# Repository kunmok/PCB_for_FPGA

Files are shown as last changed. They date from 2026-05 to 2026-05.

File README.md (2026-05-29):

# XEM7310 FPGA Breakout Board

Custom breakout / interface board for the
[Opal Kelly XEM7310](https://opalkelly.com/products/xem7310/) FPGA module, designed by
**Kunmo Kim** in Altium Designer at the **Berkeley Wireless Research Center (BWRC)**.

It mates to the XEM7310 through two mezzanine connectors and fans the FPGA's scan-chain,
analog, and digital signals out to the main/DUT board —
[pcb-for-128GSPS-adc-based-serdes](https://github.com/kunmok/pcb-for-128GSPS-adc-based-serdes) —
over a Samtec FFSD cable, while generating the bank I/O supplies and providing the level
shifting, clock probes, debug, and I²C support needed for bring-up and characterization.

XEM7310 FPGA Breakout Board (v0.5)

> 📷 Photo shows the older **v0.5**; the latest revision fixes several bugs and uses a slightly
> cheaper BOM.
> 📄 Full schematic drawing: [`FPGA_breakout_board.pdf`](FPGA_breakout_board.pdf).

## At a glance

| | |
|---|---|
| FPGA module | Opal Kelly XEM7310 |
| PCB | 4-layer; fabricated & assembled by [JLCPCB](https://jlcpcb.com/) |
| `MC2` bank | LVCMOS12 — 1.2 V (TPS7A5701, adjustable) |
| `MC1` bank | LVCMOS33 — 3.3 V (TLV1117LV33) |
| Power in | 5 V — barrel jack / banana / VBUS, TVS-protected |
| Power-up order | +5 V → +1.2 V (VCCO_MC2) → +3.3 V (VCCO_MC1) |
| Main-board link | Samtec FFSD cable, ≈100 Ω, 100 Ω series-terminated |
| Debug / probe | JTAG (ILA), 2× SMA (50 Ω), I²C (Qwiic) |

## Power

Input is 5 V via the barrel jack (`J_JACK`), banana jacks (`VDCIN_CONN` / `GND_CONN`), or
VBUS, protected by a TVS diode (`D3`). Two on-board LDOs generate the FPGA bank I/O supplies:

| Bank | I/O standard | Supply | LDO |
|---|---|---|-----|
| `MC2` | LVCMOS12 | 1.2 V — adjustable via `P1V2_POT` (Bourns 3266W-1-503, 50 kΩ) | TPS7A5701 (`U5`) |
| `MC1` | LVCMOS33 | 3.3 V | TLV1117LV33 (`U1`) |

`MC1` runs at 3.3 V because the on-chip **LT3074**'s enable input requires a 3.3 V signal.

> ⚠️ **Power-up sequence (external 1.2 V supply)** — required for correct operation, not to
> prevent damage. Follow the schematic order **+5 V → +1.2 V (VCCO_MC2) → +3.3 V (VCCO_MC1)**.
> Before driving 1.2 V into `VCCO_MC2`, isolate the XEM7310's own supply path (**do not touch
> FB8** per the schematic) to avoid back-driving the module. See Opal Kelly's
> [Powering the XEM7310](https://docs.opalkelly.com/xem7310/powering-the-xem7310/) for the
> module's power requirements.

The XEM7310 `PG_5V5` power-good flag crosses the voltage boundary via **two-step level
shifting** (two SN74LV1T34 buffers, `U_LS1` / `U_LS2`) — the reason the sequence above matters.

## Clock-test quad (`CLKQUAD`)

Optional scan-chain interface (`J_CLKQUAD`, Samtec STMM-107) for clock testing — used **only**
to measure **CLK jitter** and **ILRO lock status**, otherwise kept off. Because high scan speed
isn't needed, it runs through a dedicated **SN74AXC8T245** translator (`U2`) instead of LVCMOS
I/O, keeping the FPGA banks free.

## High-speed ADC data interface (SMA)

Two SMA connectors (Bel Cinch 142-0761-881, 26.5 GHz) on **50 Ω microstrip** carry:

- **`MEM_CLK`** — 100 MHz clock, FPGA → SerDes board.
- **`MEM_DATA_I`** — 100 Mbps retimed ADC output data, SerDes board → FPGA. Tested up to
  **200 Mbps**; likely capable of more, but untested beyond what this setup needed.

Together these two signals drive the SerDes board's **on-chip memory**: `MEM_CLK` clocks the
read-out while `MEM_DATA_I` streams the stored samples back to the FPGA, letting the FPGA read
out the retimed ADC data samples held in memory.

## FFSD cable

Scan / analog / digital signals reach the
[main board](https://github.com/kunmok/pcb-for-128GSPS-adc-based-serdes) over a Samtec FFSD
ribbon cable (`J_ESHF`, ESHF-125-01-L-D-SM), whose characteristic impedance was measured at
**≈100 Ω** in the lab. Matching **100 Ω series resistors** (`R4`–`R31`, 0402) sit close to the
connector on the driver side.

## Control & configuration

Most configuration signals originate from the **XEM7310 FPGA**, with a **Microchip
MCP2221A** USB-to-I²C/UART bridge providing an alternate path for some of them.
- I2C Control: Special thanks to @nonNoise for their [PyMCP2221A repository](https://github.com/nonNoise/PyMCP2221A), which was instrumental in implementing I2C control via the MCP2221A for this project.

**Scan chains** — all scan-chain signals are driven by the FPGA. The main board carries two
independent chains: a **5-pin** chain for analog-circuit control and a **7-pin** chain for
digital-circuit control. Both chains run at **12.5 Mbps**. The 7-pin chain runs on a
**two-phase non-overlapping clock**, making it immune to hold-time violations.

**LDO enable** — normally driven by the FPGA, but can alternatively be driven from the
**MCP2221A GPIO** pins.

**I²C** — normally handled by the **MCP2221A** at **100 kbps**; the FPGA can drive it as a
fallback.

## Connectors & key parts

| Function | Part | Designator(s) |
|---|---|---|
| XEM7310 mezzanine | Samtec BTE-040-01-F-D-A (0.8 mm) | `MC1`, `MC2` |
| FFSD cable | Samtec ESHF-125-01-L-D-SM | `J_ESHF` |
| CLKQUAD header | Samtec STMM-107-02-L-D | `J_CLKQUAD` |
| SMA clk/data (26.5 GHz) | Bel Cinch 142-0761-881 | `J_MEM_CLK`, `J_MEM_DATA` |
| JTAG (ILA, 2×7, 2 mm) | Molex 87831-1420 | `J_JTAG` |
| I²C — Qwiic / headers | Würth 61300311121 / Samtec TSW | `P1` / `J_SCL*`, `J_SDA*` |
| USB-to-I²C/UART bridge | Microchip MCP2221A | `U3` |
| 1.2 V LDO (5 A, adj.) | TI TPS7A5701RTER | `U5` |
| 3.3 V LDO (1 A) | TI TLV1117LV33DCYR | `U1` |
| Level translator (CLKQUAD) | TI SN74AXC8T245RHLR | `U2` |
| Level shifter (PG_5V5) | TI SN74LV1T34DBVR | `U_LS1`, `U_LS2` |
| 100 Ω series term (0402) | Panasonic ERJ-2RKF1000X | `R4`–`R31` |
| TVS / jack / banana | SMAJ6.0CA / CUI PJ-102AH / Keystone 575-4 | `D3` / `J_JACK` / `*_CONN` |

Full BOM:
[`FPGA_breakout_board_BOM.xlsx`](Project%20Outputs%20for%20FPGA_breakout_board/FPGA_breakout_board_BOM.xlsx).

## Files

4-layer stack-up (Top / two inner planes / Bottom); DRC passes with **0 violations**.

```
BoardTop.SchDoc                Top-level schematic
FPGA_breakout_board_v1.PcbDoc  PCB layout
FPGA_breakout_board.PrjPcb     Altium project
FPGA_breakout_board.pdf        Schematic + fabrication drawings
FPGA_breakout_board.OutJob     Output-generation job
Component/                     Symbols, footprints, 3D/STEP models, vendor libs
Project Outputs for .../       Gerbers, NC drill, BOM, pick & place, DRC report
```

Open `FPGA_breakout_board.PrjPcb` in Altium Designer. Run the `.OutJob` to regenerate
manufacturing outputs; ready-to-send Gerbers are in `Project Outputs .../Gerber.zip`.

## Author

Designed by **Kunmo Kim** — [kunmo.kim0225@gmail.com](mailto:kunmo.kim0225@gmail.com) ·
[kunmok.github.io](https://kunmok.github.io)

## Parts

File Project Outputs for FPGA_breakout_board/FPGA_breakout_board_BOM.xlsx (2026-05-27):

Line # | Name | Description | Designator | Quantity | Manufacturer 1 | Manufacturer Part Number 1 | Supplier 1 | Supplier Part Number 1 | Supplier Unit Price 1 | Supplier Subtotal 1
 | MTG | Mounting hole | MH1, MH2, MH3, MH4, MH5, MH6, MH7, MH8 | 8
1 | LLL1U4R60G435ME22D | Cap Ceramic Monolithic 4.3uF 20% 4V X5R 15% 02404 (0610M) | C1, C2, C4, C5, C6, C7, C8, C10, C11, C13, C16, C17, C18, C20 | 14 | Murata | LLL1U4R60G435ME22D | Digikey | 490-LLL1U4R60G435ME22DCT-ND | 0.073 | 1.02
2 | ESHF-125-01-L-D-SM | No Description Available | J_ESHF | 1 | Samtec | ESHF-125-01-L-D-SM | Digikey | SAM15560-ND | 7.15 | 7.15
3 | STMM-107-02-L-D | Connector Header Surface Mount 14 position 0.079 (2.00mm) | J_CLKQUAD | 1 | Samtec | STMM-107-02-L-D | Mouser | 200-STMM10702LD | 4.58 | 4.58
4 | EEF-CX0J101R | CAP ALUM POLY 100UF 20% 6.3V SMD | C9 | 1 | Panasonic | EEF-CX0J101R | Avnet | 62W7349 | 1.19 | 1.19
5 | SMAJ6.0CAHE3/5A | Transient Voltage Suppressor, 6.40 to 231 V, 6 V Stand-off Voltage, Bi-Directional, -55 to 155 degC, 2-pin DO-214AC, Pb-Free, Tape and Reel | D3 | 1 | Vishay Semiconductors | SMAJ6.0CAHE3_A/H | Mouser | 78-SMAJ6.0CAHE3_A/H | 0.61 | 0.61
6 | LTST-C190KGKT | LED GREEN CLEAR CHIP SMD | D_1V2, D_5V5 | 2 | Vishay Lite-On | LTST-C190KGKT | Mouser | 859-LTST-C190KGKT | 0.13 | 0.26
7 | PJ-102AH | DC power connector - high current | J_JACK | 1 | CUI Devices | PJ102AH | Digikey | CP-102AH-ND | 0.76 | 0.76
8 | TSW-102-07-G-S | CONN HEADER VERT 2POS 2.54MM | J_SCL1, J_SCL2, J_SDA1, J_SDA2 | 4 | Samtec | TSW-102-07-G-S | Avnet | TSW-102-07-G-S | 0.147 | 0.588
9 | 575-4 | Banana Jack, Non-Insulated, 1-Pin THD, RoHS, Bulk | GND_CONN, VDCIN_CONN | 2 | Keystone Electronics | 575-4 | Newark | 99H8227 | 0.773 | 1.55
10 | 06035C104KAT2A | General Purpose Ceramic Capacitor, 0603, 100nF, 10%, X7R, 15%, 50V | C3 | 1 | Kyocera AVX | 06035D104KAT2A | Newark | 95W9226 | 0.005 | 0.005
11 | 87831-1420 | Header, Pitch 2 mm, 2 x 7 Position, Height 6.4 mm, Tail Length 2.5 mm, -55 to 105 degC, RoHS, Tube | J_JTAG | 1 | Molex | 87831-1420 | Arrow Electronics | 87831-1420 | 0.84 | 0.84
12 | 5019 |  | J_GP0, J_GP1, J_GP2, J_GP3, J_RST, J_VBUS | 6 | Keystone Electronics | 5019 | Newark | 59Y8500 | 0.283 | 1.7
13 | ERJ-3EKF1000V |  | R_SCL, R_SDA | 2 | Panasonic | ERJ-3EKF1000V | Newark | 85Y8496 | 0.099 | 0.198
14 | ERJ-8ENF2001V |  | R1, R2, R3 | 3 | Panasonic | ERJ-8ENF2001V | Newark | 65T8855 | 0.019 | 0.057
15 | 5001 | PC TEST POINT MINIATURE BLACK | J_GND1, J_GND2, J_GND3, J_GND4 | 4 | Keystone Electronics | 5001 | Newark | 62W5135 | 0.155 | 0.62
16 | 142-0761-881 | SMA High Freq End Launch Jack Receptacle, PCB Mount, 10 MIL Pin, 26.5 GHz, 50 Ohm, -65 to 165 degC, Round Body Radius 6.27 mm, Body Length 9.52 mm, RoHS | J_MEM_CLK, J_MEM_DATA | 2 | Bel Cinch | 142-0761-881
17 | 5000 | PC TEST POINT MINIATURE RED | J_1V0, J_1V2, J_VCCO_MC1 | 3 | Keystone Electronics | 5000 | Newark | 07J9695 | 0.131 | 0.393
18 | BTE-040-01-F-D-A | 0.8mm high-density header | MC1, MC2 | 2 | Samtec | BTE-040-01-F-D-A | Digikey | SAM9060-ND | 3.38 | 6.76
19 | 61300311121 |  | P1 | 1 | Wurth Electronics | 61300311121 | Digikey | 732-5316-ND | 0.12 | 0.12
20 | 878980304 | No Description Available | P1V2_EN | 1 | Molex | 87898-0304 | Digikey | WM20562-ND | 0.7 | 0.7
21 | 3266W-1-503LF | No Description Available | P1V2_POT | 1 | Bourns | 3266W-1-503LF | Avnet | 3266W-1-503LF | 2.77 | 2.77
22 | TLV1117LV33DCYR | Single Output LDO, 1 A, Fixed 3.3 V Output, 2 to 5.5 V Input, 4-pin SOT-223 (DCY), -40 to 125 degC, Green (RoHS & no Sb/Br) | U1 | 1 | Texas Instruments | TLV1117LV33DCYR | Mouser | 595-TLV1117LV33DCYR | 0.22 | 0.22
23 | ERJ-3EKF2002V |  | R8, R9, R10 | 3 | Panasonic | ERJ-3EKF2002V | Mouser | 667-ERJ-3EKF2002V | 0.12 | 0.36
24 | ERJ-3EKF4022V | RES SMD 40.2K OHM 1% 1/10W 0603 | R7 | 1 | Panasonic | ERJ-3EKF4022V | Newark | 65T8448 | 0.005 | 0.005
25 | MMBT3904TT1G | General Purpose Transistor, NPN Silicon, 3-Pin SC-75, Pb-Free, Tape and Reel | Q1 | 1 | onsemi | MMBT3904TT1G | Avnet | 88H4787 | 0.032 | 0.032
26 | ERJ-2RKF1000X | Chip Resistor, 100 Ohm, +/- 1%, 100 mW, -55 to 155 degC, 0402 (1005 Metric), RoHS, Tape and Reel | R4, R5, R6, R11, R12, R13, R14, R15, R16, R17, R18, R19, R24, R25, R26, R27, R28, R29, R30, R31 | 20 | Panasonic | ERJ-2RKF1000X | Avnet | 64R5246 | 0.017 | 0.34
27 | TSW-107-07-G-S | CONN HEADER VERT 7POS 2.54MM | J1, J2 | 2 | Samtec | TSW-107-07-G-S | Avnet | TSW-107-07-G-S | 0.15568 | 0.31136
28 | SN74LV1T34DBVR | IC BUF NON-INVERT 5.5V SOT23-5 | U_LS1, U_LS2 | 2 | Texas Instruments | SN74LV1T34DBVR | Arrow Electronics | SN74LV1T34DBVR | 0.162 | 0.324
29 | TPS7A5701RTER | No Description Available | U5 | 1 | Texas Instruments | TPS7A5701RTER | Mouser | 595-TPS7A5701RTER | 11.72 | 11.72
30 | ERJ-8GEYJ202V |  | R20, R21 | 2 | Panasonic | ERJ-8GEYJ202V | Digikey | P2.0KECT-ND | 0.13 | 0.26
31 | SN74AXC8T245RHLR | IC TRNSLTR BIDIRECTIONAL 24VQFN | U2 | 1 | Texas Instruments | SN74AXC8T245RHLR | Arrow Electronics | SN74AXC8T245RHLR | 0.99 | 0.99

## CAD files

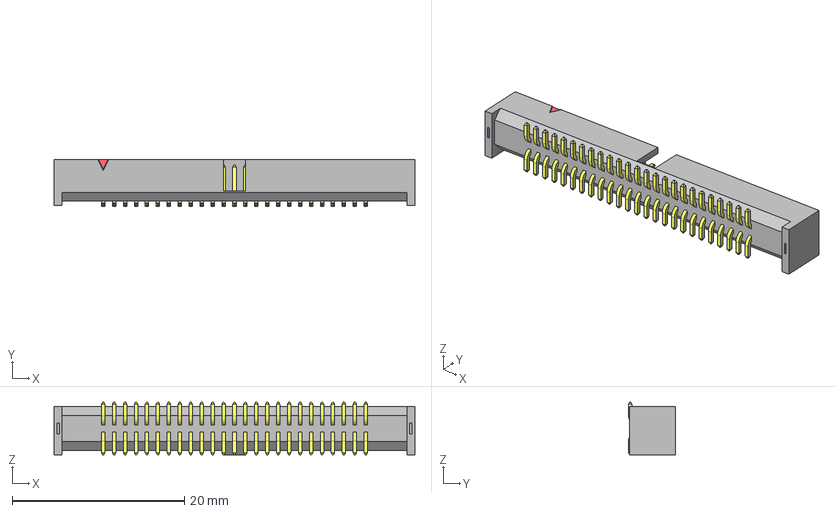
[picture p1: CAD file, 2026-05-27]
Component/ESHF_conn/ESHF-125-01-L-D-SM.stp
41.9 x 5.46 x 6.10 mm
ESHF-125-01-L-D-SM_t
ESHF-125-01-L-D-SM_p
ESHF-125-01-L-D-SM_k
ESHF-125-01-L-D-SM_tr

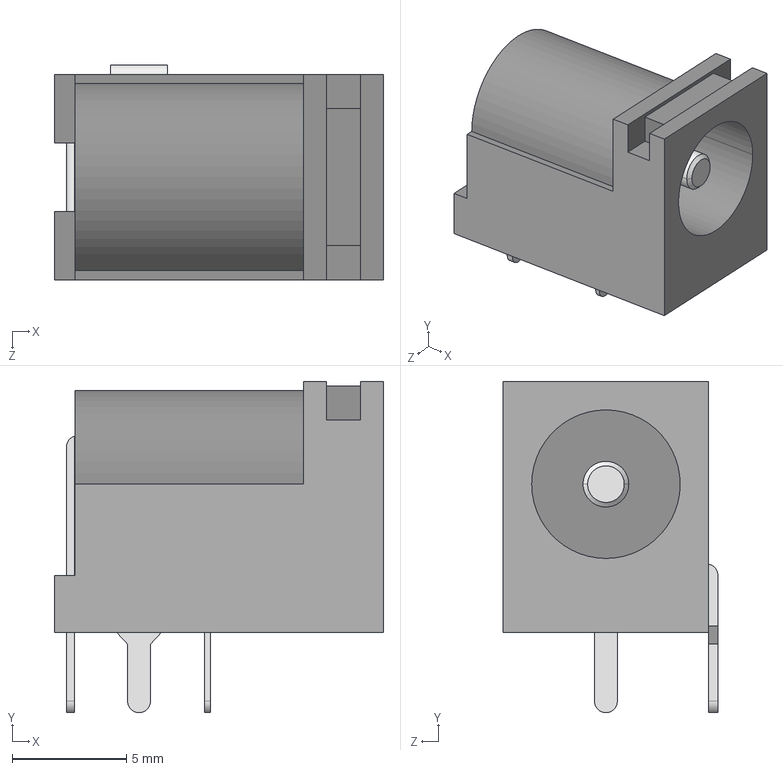
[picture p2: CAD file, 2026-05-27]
Component/PJ_102AH/PJ-102AH.STEP
14.4 x 14.5 x 9.40 mm

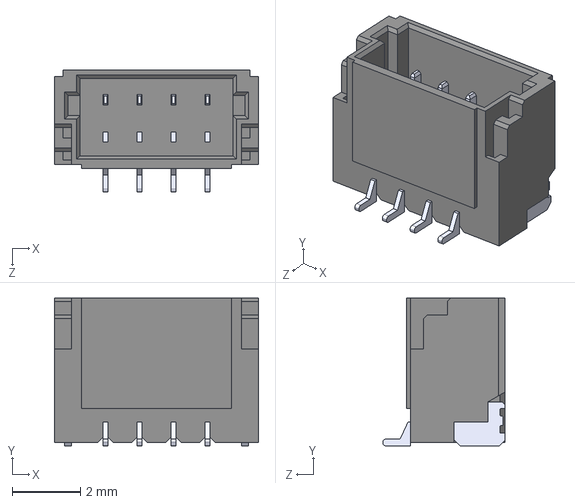
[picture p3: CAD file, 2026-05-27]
Component/qwiic connector/4328--3DModel-STEP-269445.STEP
6.00 x 4.35 x 3.60 mm

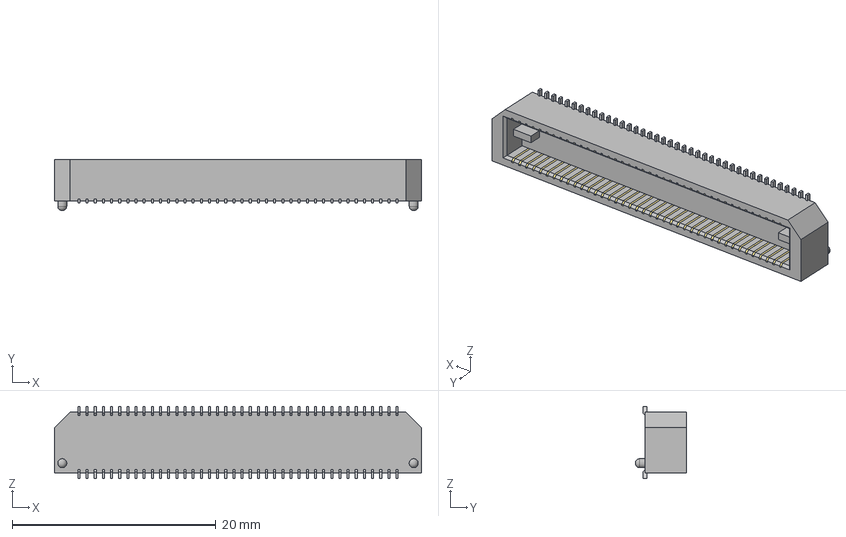
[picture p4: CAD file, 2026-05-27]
Component/SAMTEC_BTE04001FDA/BTE-040-01-F-D-A.stp
36.0 x 5.02 x 7.11 mm
BTE-040-01-D-A_terminal
T-1S39-040-01-F
T-1S39-040-01-F-2

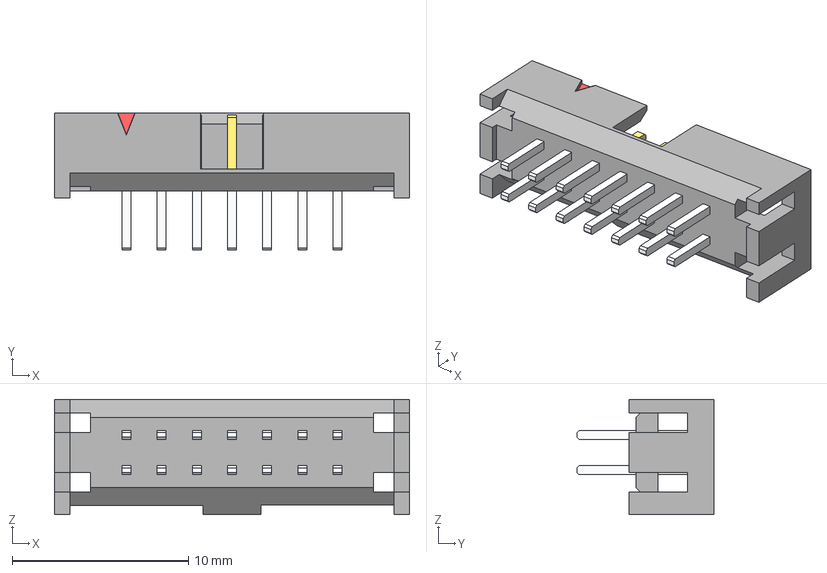
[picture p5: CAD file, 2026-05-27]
Component/STMM-107-02-L-D/STMM-107-02-L-D.stp
20.2 x 7.80 x 6.54 mm
STMM-107-02-D-_header
STMM-First_Position_Indicator
T-1S13-07-02-DLstmm
T-1S13-07-02-DL2stmm

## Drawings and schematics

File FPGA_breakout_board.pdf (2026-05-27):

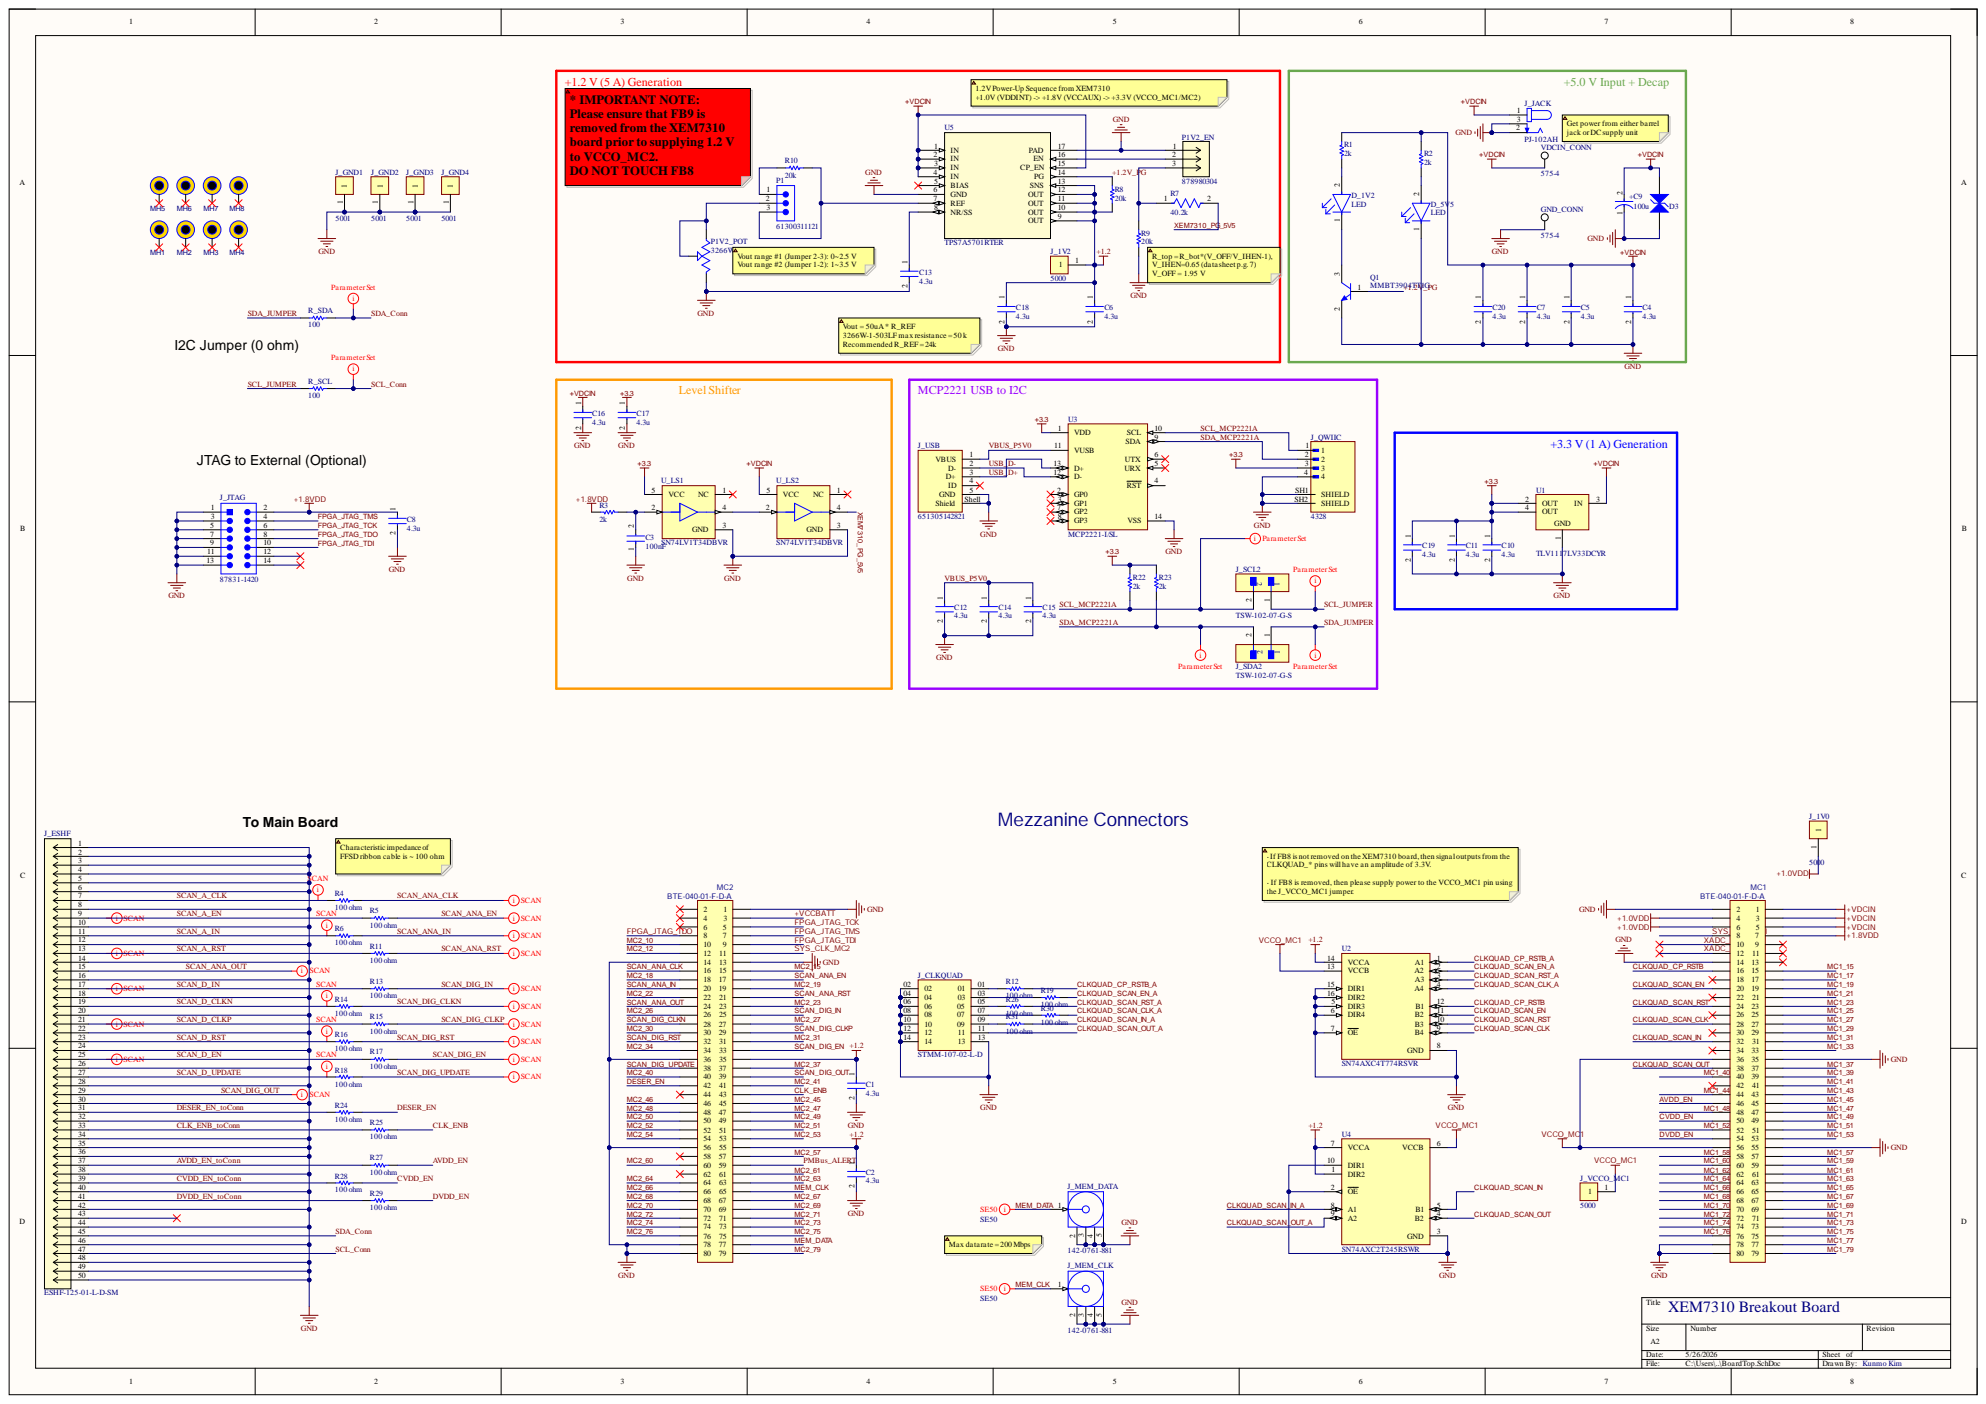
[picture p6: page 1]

+1.0V (VDDINT) -> +1.8V (VCCAUX) -> +3.3V (VCCO_MC1/MC2) * IMPORTANT NOTE:
Please ensure that FB9 is
removed from the XEM7310
board prior to supplying 1.2 V
to VCCO_MC2.
DO NOT TOUCH FB8

Get power from either barrel
jack orDC supply unit

3 | 61300311121 | NR/SS 8 | 40.2k XEM7310_PG_5V5

JTAG to External (Optional)

USB_D+ | D- 12 | 4 4

Characteristic impedance of
FFSD ribbon cable is ~ 100 ohm

-If FB8 is not removed on the XEM7310 board,then signaloutputs from the
CLKQUAD_* pins will have an amplitude of 3.3V.

- If FB8 is removed, then please supply power to the VCCO_MC1 pin using
the J_VCCO_MC1 jumper.

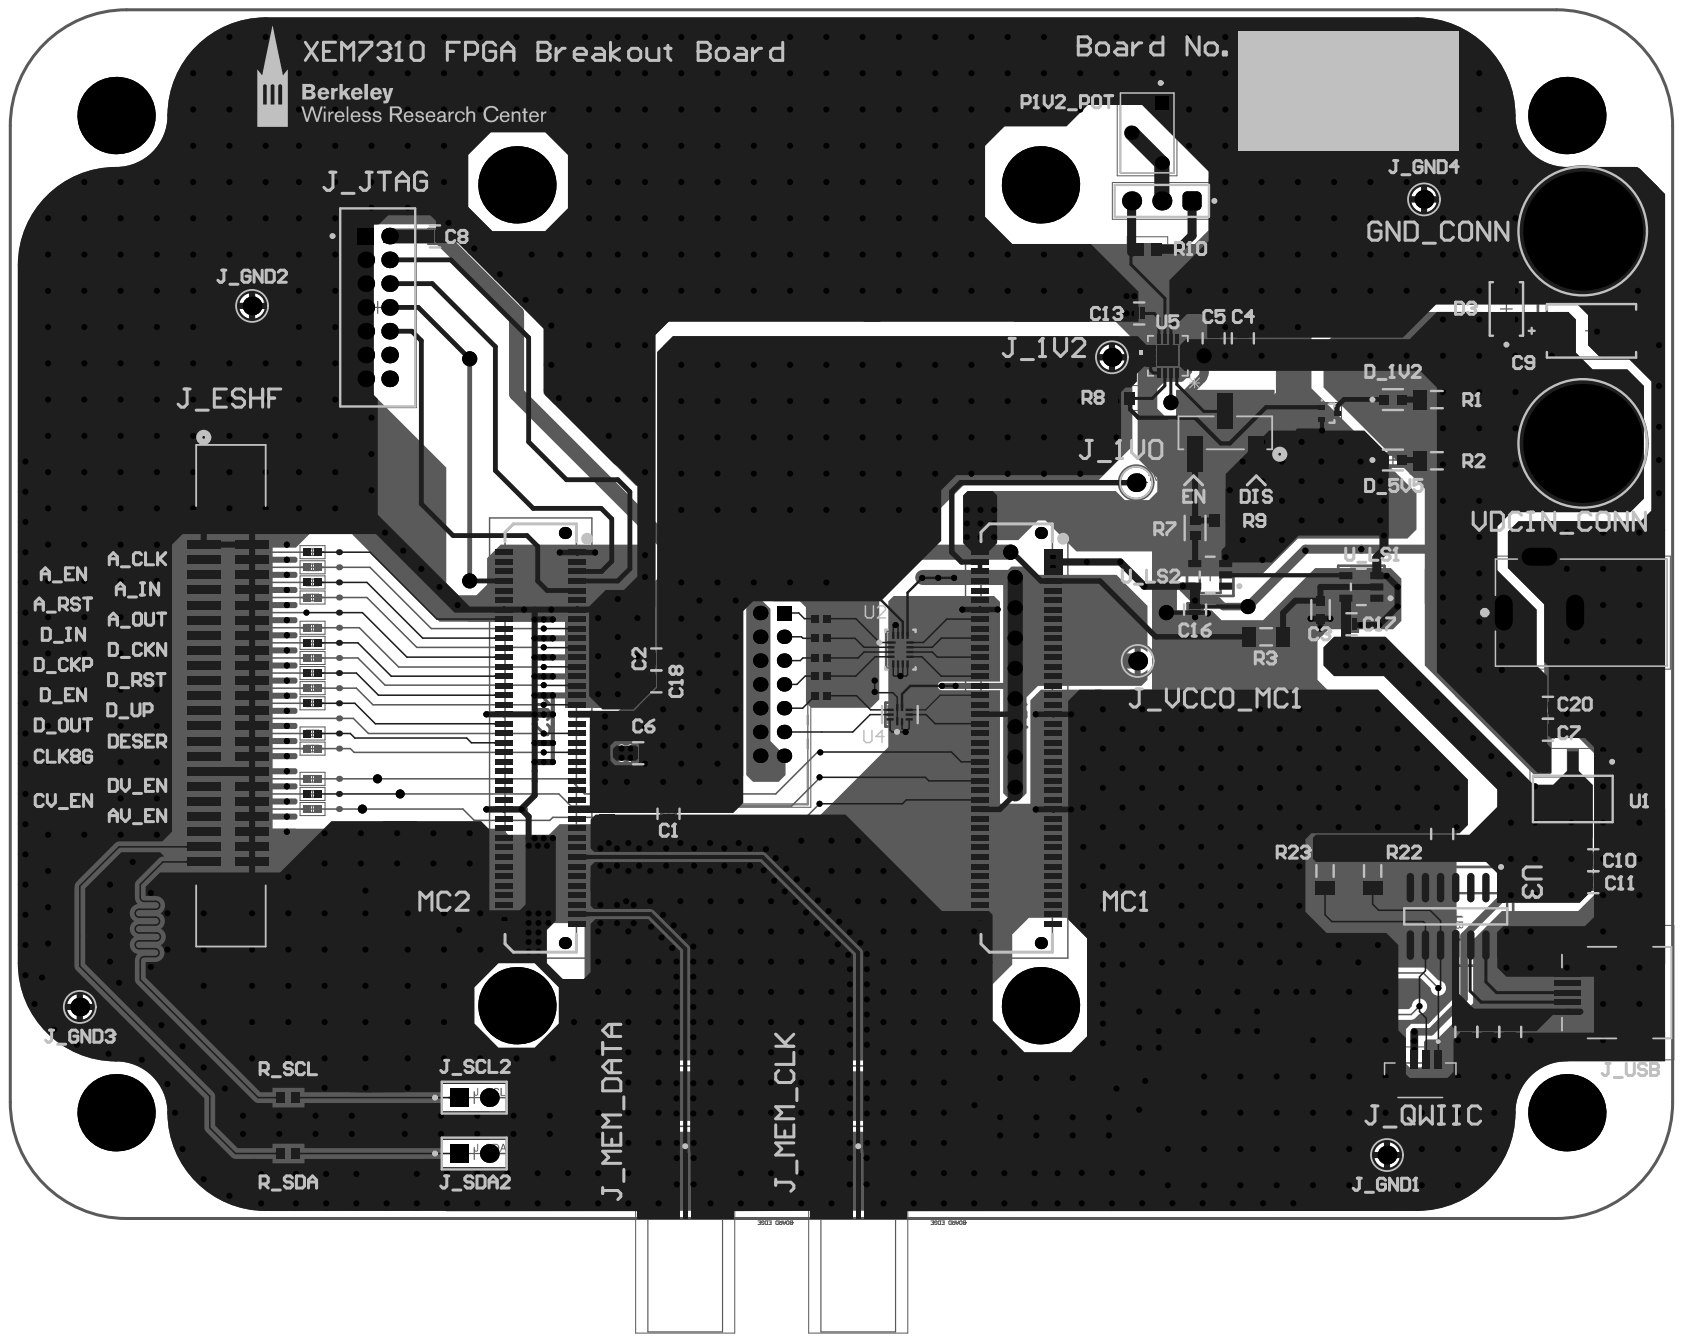
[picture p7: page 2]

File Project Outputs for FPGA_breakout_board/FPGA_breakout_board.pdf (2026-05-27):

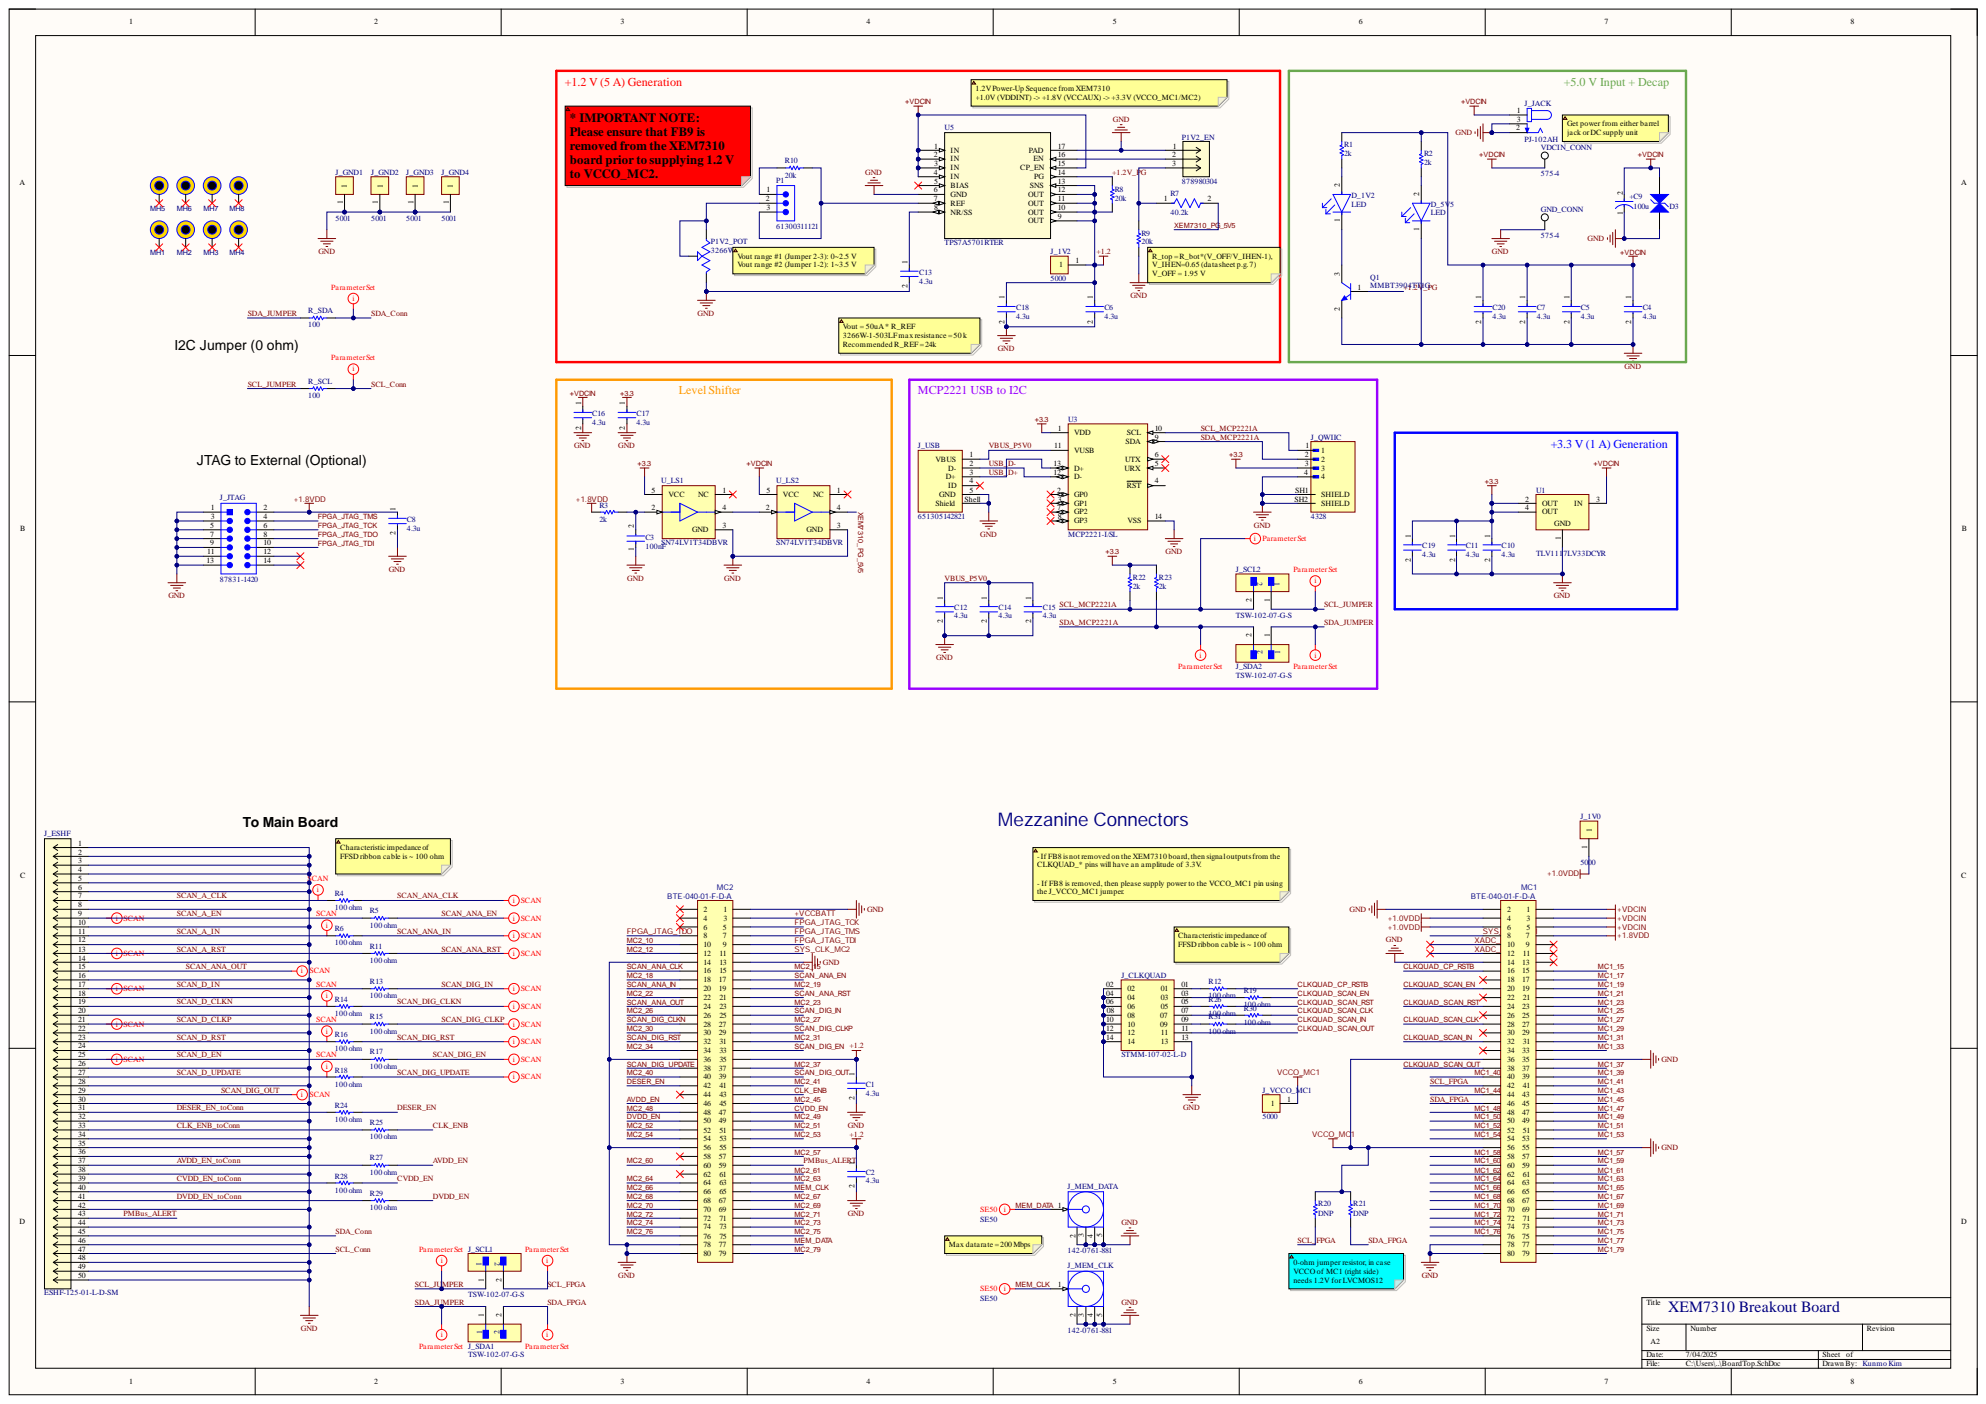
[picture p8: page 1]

* IMPORTANT NOTE:
Please ensure that FB9 is
removed from the XEM7310
board prior to supplying 1.2 V
to VCCO_MC2.

Get power from either barrel
jack orDC supply unit

3 | 61300311121 | NR/SS 8 | 40.2k XEM7310_PG_5V5

JTAG to External (Optional)

USB_D+ | D- 12 | 4 4

Characteristic impedance of
FFSD ribbon cable is ~ 100 ohm

-If FB8 is not removed on the XEM7310 board,then signaloutputs from the
CLKQUAD_* pins will have an amplitude of 3.3V.

- If FB8 is removed, then please supply power to the VCCO_MC1 pin using
the J_VCCO_MC1 jumper.

0-ohm jumper resistor, in case
VCCO of MC1 (right side)
needs 1.2V for LVCMOS12

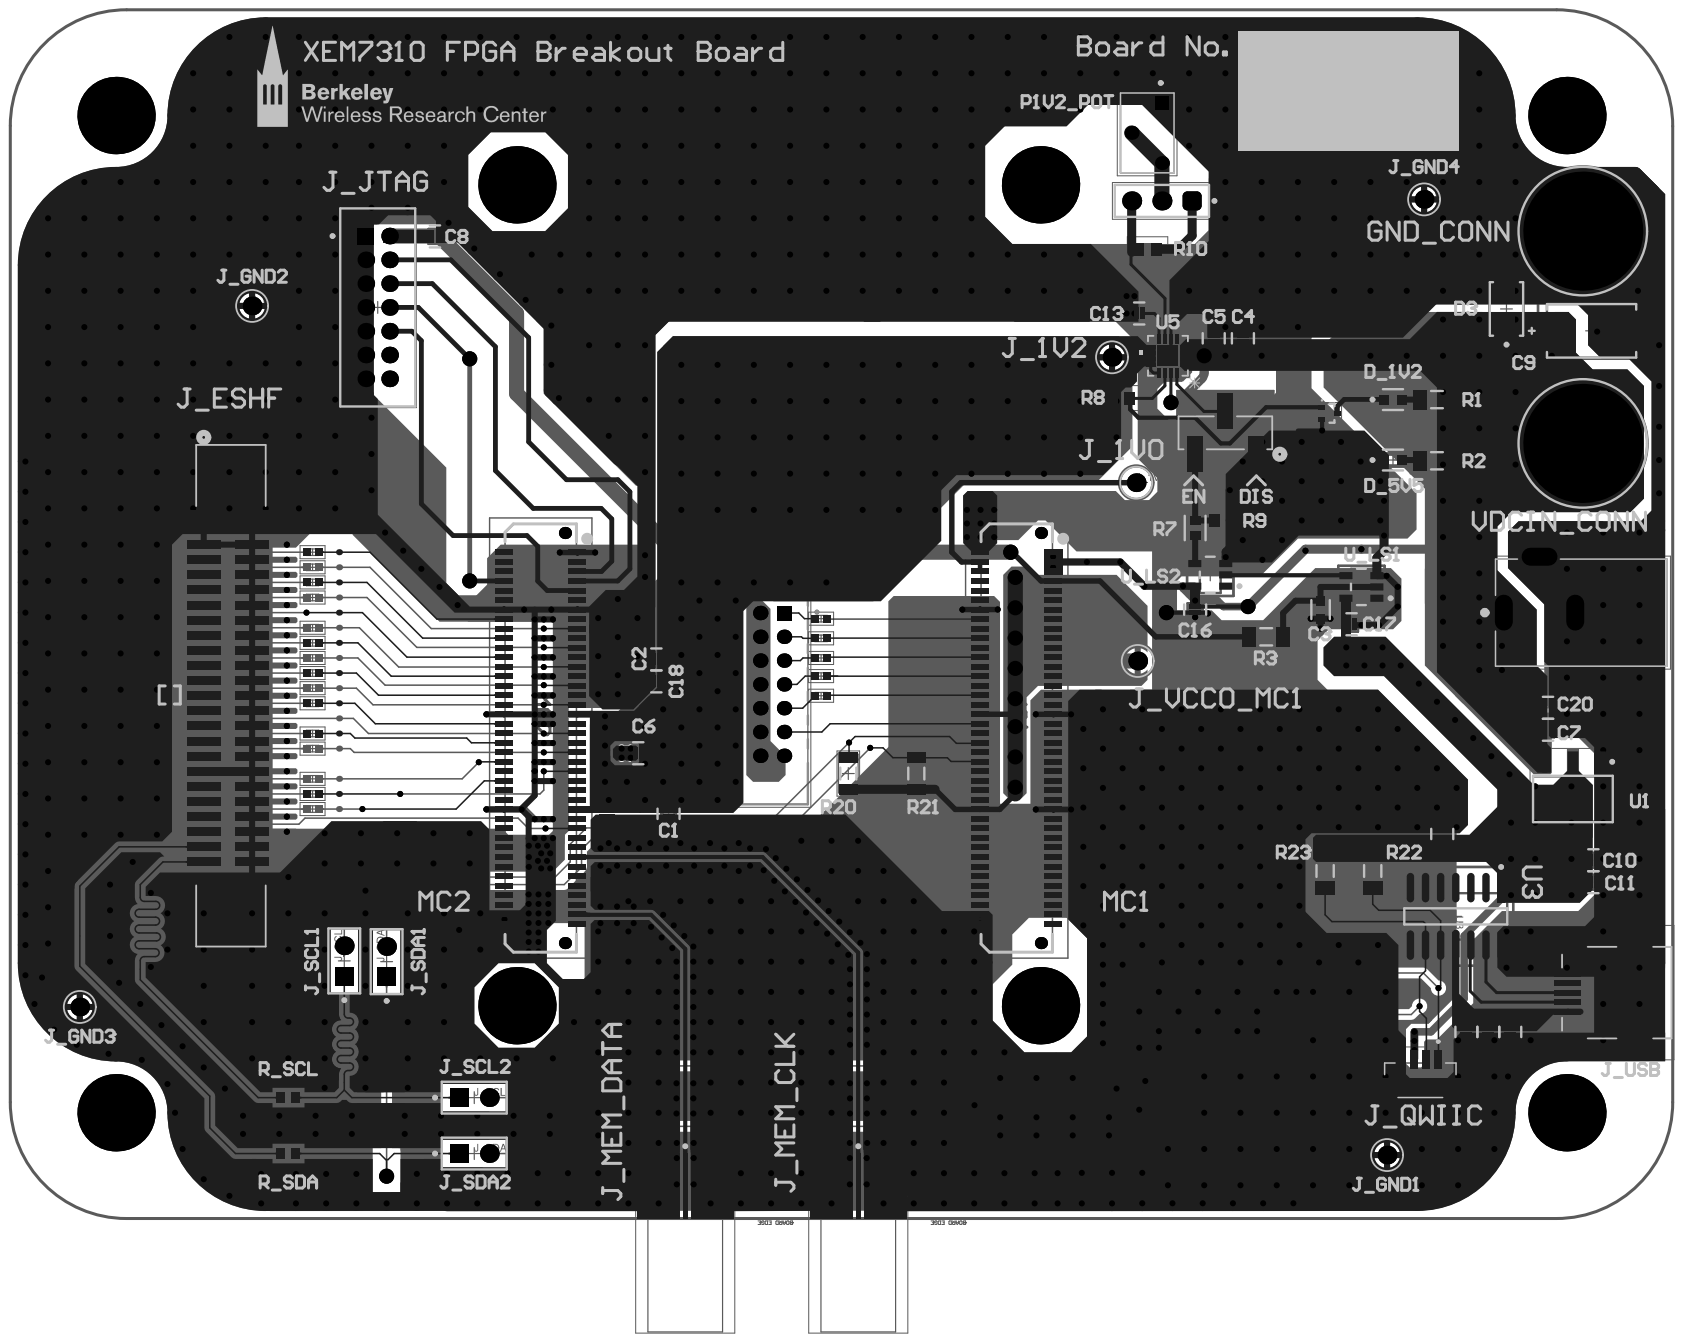
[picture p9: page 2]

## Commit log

2026-05-27 updated PDF file
    [FPGA_breakout_board.PrjPcb]
2026-05-27 updated FPGA breakout board PDF file
    [BoardTop.SchDoc]

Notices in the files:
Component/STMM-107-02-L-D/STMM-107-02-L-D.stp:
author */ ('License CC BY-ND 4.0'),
